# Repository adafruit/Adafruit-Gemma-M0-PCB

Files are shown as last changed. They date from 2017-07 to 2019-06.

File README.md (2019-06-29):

## Adafruit Gemma M0 PCB

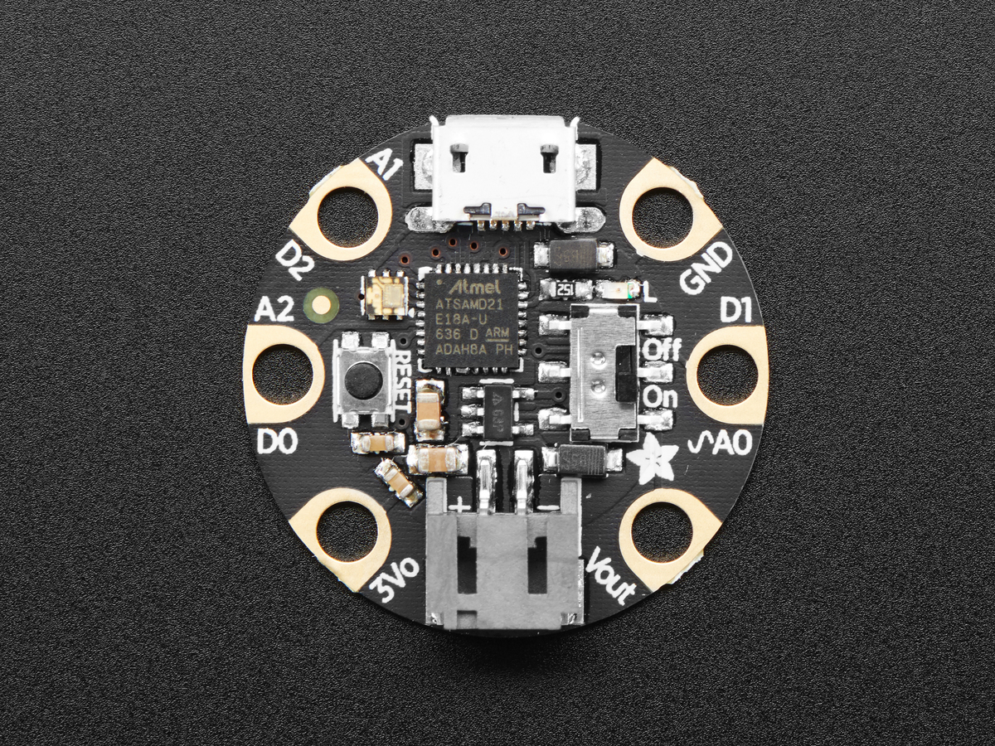
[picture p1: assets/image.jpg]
<a href="http://www.adafruit.com/products/3501"><br/>
Click here to purchase one from the Adafruit shop</a>

PCB files for the Adafruit Gemma M0. 

This is the CAD & PCB data for the Adafruit Gemma. PCB format is EagleCAD schematic and board layout

For more details, check out the product page at
* https://www.adafruit.com/products/3501

### Description

The Adafruit Gemma M0 is a super small microcontroller board, with just enough built-in to create many simple projects. It may look small and cute: round, about the size of a quarter, with friendly alligator-clip sew pads. But do not be fooled! The Gemma M0 is incredibly powerful! We've taken the same form factor we used for the original ATtiny85-based Gemma and gave it an upgrade. The Gemma M0 has swapped out the lightweight ATtiny85 for a ATSAMD21E18 powerhouse.

The Gemma M0 will super-charge your wearables! It's just as small, and it's easier to use, so you can do more.

The most exciting part of the Gemma M0 is that while you can use it with the Arduino IDE, we are shipping it with CircuitPython on board. When you plug it in, it will show up as a very small disk drive with main.py on it. Edit main.py with your favorite text editor to build your project using Python, the most popular programming language. No installs, IDE or compiler needed, so you can use it on any computer, even ChromeBooks or computers you can't install software on. When you're done, unplug the Gemma M0 and your code will go with you.

### License

Adafruit invests time and resources providing this open source design, please support Adafruit and open-source hardware by purchasing products from [Adafruit](https://www.adafruit.com)!

Designed by Limor Fried/Ladyada for Adafruit Industries.

Creative Commons Attribution/Share-Alike, all text above must be included in any redistribution. See license.txt for additional details.

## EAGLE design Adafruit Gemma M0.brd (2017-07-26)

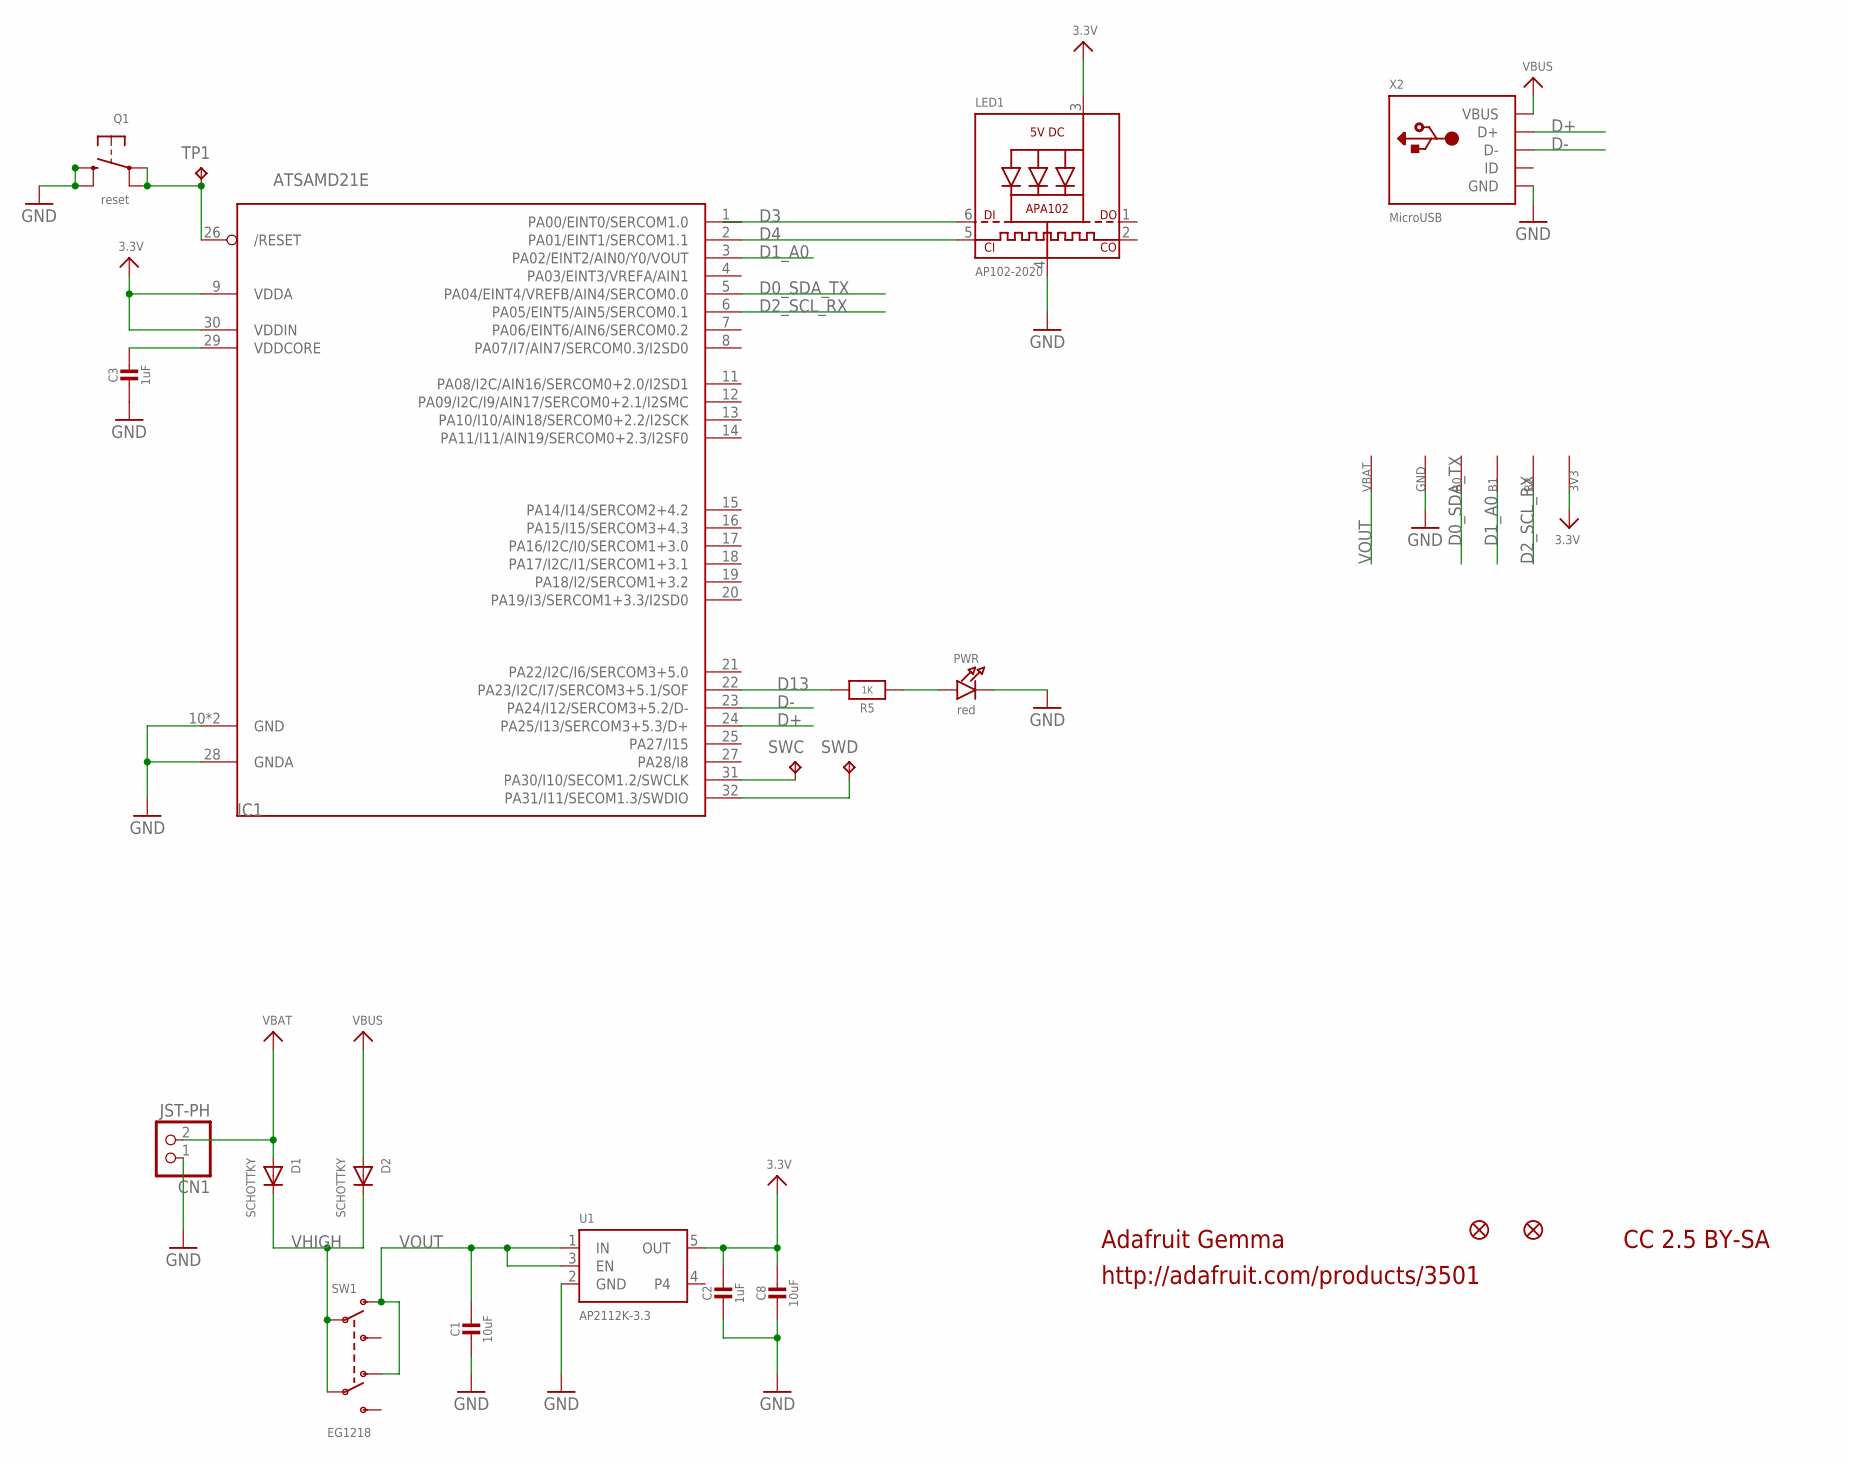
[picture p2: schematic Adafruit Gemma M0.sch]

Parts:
3V3: SEWTAP-ALLIGATOR; SEWALLI
B0, B1, B2: SEWTAP-ALLIGATOR; SEWALLI
C1, C8: 10uF; 0805-NO
C2, C3: 1uF; 0603-NO
CN1: JST-PH; JSTPH2
D1, D2: SCHOTTKY; SOD-123FL
GND: SEWTAP-ALLIGATOR; SEWALLI
IC1: ATSAMD21E; QFN32_5MM
LED1: AP102-2020; APA102_2020
PWR: red; CHIPLED_0603_NOOUTLINE
Q1: reset; BTN_KMR2_4.6X2.8
R5: 1K; 0603-NO
SW1: EG1218; EG1390
SWC: TPTP15R; TP15R
SWD: TPTP15R; TP15R
TP1: TPTP16R; TP16R
U1: AP2112K-3.3; SOT23-5
U$1, U$6: FIDUCIAL_1MM
VBAT: SEWTAP-ALLIGATOR; SEWALLI
X2: MicroUSB; 4UCONN_20329_V2

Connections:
3.3V: 3V3.P$1, C2.1, C8.1, IC1.9 (VDDA), IC1.30 (VDDIN), LED1.3 (VDD), U1.5 (OUT)
!RESET: IC1.26 (/RESET), Q1.A, Q1.A' (P1), TP1.TP
D0_SDA_TX: B0.P$1, IC1.5 (PA04/EINT4/VREFB/AIN4/SERCOM0.0)
D1_A0: B1.P$1, IC1.3 (PA02/EINT2/AIN0/Y0/VOUT)
D2_SCL_RX: B2.P$1, IC1.6 (PA05/EINT5/AIN5/SERCOM0.1)
D3: IC1.1 (PA00/EINT0/SERCOM1.0), LED1.6 (DI)
D4: IC1.2 (PA01/EINT1/SERCOM1.1), LED1.5 (CKI)
D13: IC1.22 (PA23/I2C/I7/SERCOM3+5.1/SOF), R5.2
D+: IC1.24 (PA25/I13/SERCOM3+5.3/D+), X2.D+
D-: IC1.23 (PA24/I12/SERCOM3+5.2/D-), X2.D-
GND: C1.2, C2.2, C3.2, C8.2, CN1.1, GND.P$1, IC1.10 (GND), IC1.28 (GNDA), IC1.33 (GND), LED1.4 (GND), PWR.C, Q1.B (S), Q1.B' (S1), U1.2 (GND), X2.BASE@1 (GND), X2.BASE@2 (GND), X2.GND, X2.SPRT@1 (GND), X2.SPRT@2 (GND), X2.SPRT@3 (GND), X2.SPRT@4 (GND)
unnamed: PWR.A, R5.1
SWCLK: IC1.31 (PA30/I10/SECOM1.2/SWCLK), SWC.TP
SWDIO: IC1.32 (PA31/I11/SECOM1.3/SWDIO), SWD.TP
VBAT: CN1.2, D1.A
VBUS: D2.A, X2.VBUS
VDDCORE: C3.1, IC1.29 (VDDCORE)
VHIGH: D1.C, D2.C, SW1.P1, SW1.P2
VOUT: C1.1, SW1.O1, SW1.O2, U1.1 (IN), U1.3 (EN), VBAT.P$1

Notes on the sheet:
Adafruit Gemma
http://adafruit.com/products/3501
CC 2.5 BY-SA

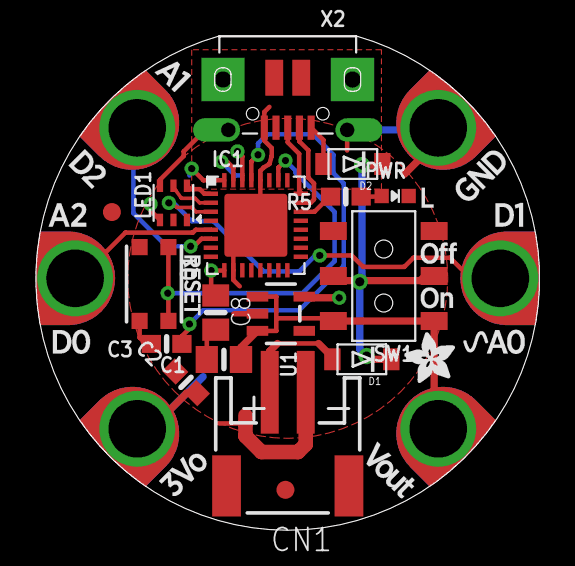
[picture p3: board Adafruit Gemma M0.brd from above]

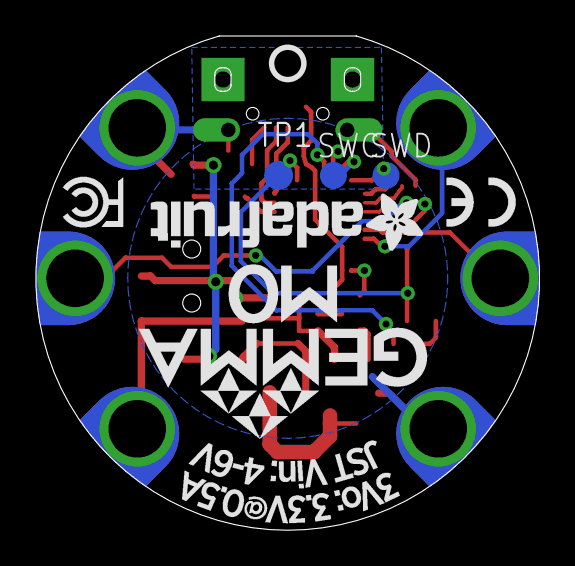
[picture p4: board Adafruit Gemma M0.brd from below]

Board: 2 copper layers, 28.0 x 27.5 mm, 29 parts (5 on the bottom side), 19 nets.

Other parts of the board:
U$7: GEMMA_M0_BOTTOM
U$8: GEMMA_M0_TOP
U$10: PCBFEAT-REV-040

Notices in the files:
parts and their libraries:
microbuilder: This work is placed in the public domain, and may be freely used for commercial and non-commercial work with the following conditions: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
